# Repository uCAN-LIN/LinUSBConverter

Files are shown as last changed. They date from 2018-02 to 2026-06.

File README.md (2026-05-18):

# USB LIN Converter (uLC)





> **Open source USB ↔ LIN bus dongle. LIN 2.1 master, slave or monitor. SLCAN-compatible virtual COM port - works on Windows, Linux and macOS with no proprietary drivers.**

<p align="center">
  USB LIN Converter (uLC) - dongle photo
</p>

The **USB LIN Converter (uLC)** is a small open-source USB dongle (STM32F042C6, ~31 × 18 mm) that lets a PC act as a LIN bus master, slave or passive monitor. It enumerates as a USB CDC virtual COM port and speaks an SLCAN-style ASCII protocol, so it bridges into Linux SocketCAN via `slcand` and works with parts of can-utils.

A commercial automotive LIN analyzer typically costs hundreds to thousands of euros. This one is around **$27** on [Tindie](https://www.tindie.com/products/lll7/usb-lin-converter/).

The LIN protocol implementation is based on [openLIN](https://github.com/open-LIN).

---

## Features

- LIN 2.1 support
- **Monitor mode** - full frame reception plus single-frame transmission
- **Master mode** - up to 15 scheduled frame slots
- **Slave mode** - up to 15 scheduled frame slots for slave simulation
- 9600 / 19200 baud rate selection
- **Optical isolation** between LIN and the USB / PC side
- Software-controlled termination resistors
- External 4.5 - 28 V powers the LIN transceiver
- Device size 31 × 18 mm (without USB connector)
- USB DFU bootloader for firmware updates
- No proprietary drivers - Linux / macOS / Windows

---

## Where to buy

| Where | Region | Link |
|---|---|---|
| **Tindie** | Worldwide | https://www.tindie.com/products/lll7/usb-lin-converter/ |
| **Lectronz** | EU | https://lectronz.com/stores/ucandevices |
| **Elty** | Poland / EU | https://elty.pl/ |
| **Kamami** | Poland / EU | https://kamami.pl/ |

---

## Quickstart

1. Plug the device into a USB port. It enumerates as a virtual COM port (`COM3` on Windows, `/dev/ttyACM0` on Linux, `/dev/cu.usbmodem*` on macOS).
2. On Windows, install the [ST Virtual COM Port driver](https://www.st.com/en/development-tools/stsw-stm32102.html). On Linux and macOS no driver is required.
3. Open the port at any baud rate (USB CDC ignores baud). Line ending must be CR (`0x0D`).
4. Power the LIN side with 4.5 - 28 V on the external supply pin.
5. Send `S0` to select 19200 baud, then `l` to enter monitor mode. Bus traffic will start to appear.

### Linux SocketCAN bridge

```bash
sudo slcand -o -s8 -t hw -S 921600 /dev/ttyACM0 slcan0
sudo ip link set slcan0 up
candump slcan0
```

### Python (pyserial) sniff snippet

```python
import serial
ser = serial.Serial('/dev/ttyACM0', timeout=1)
ser.write(b'S0\r')   # 19200 baud
ser.write(b'l\r')    # monitor mode
while True:
    line = ser.readline()
    if line:
        print(line.decode(errors='replace').strip())
```

A higher-level Python library is provided in [`python_lib/`](python_lib/) (package `ucanlintools`).

---

## ASCII command reference

All commands are ASCII terminated with CR (`0x0D`). Errors return `0x07` (BEL).

| Command | Description |
|---|---|
| `O` | Open in master mode |
| `L` | Open in slave mode |
| `l` | Open in monitor mode |
| `C` | Close LIN port |
| `Sx` | Baud: `S2` = 9600, others = 19200 |
| `V` / `v` / `N` | Hardware / firmware version / serial number query |
| `tiiildd...` | Transmit full header + data frame (id, length, data) |
| `r0iil` | Header only request (slave answers) |
| `r1ff0` | Master mode: start sending frames from schedule table |
| `r2ff0` | Clear schedule table |
| `xm` | Switch checksum: `x2` classic, `x1` enhanced |
| `T0iit1t1t2t2ldd...` | Custom frame with explicit offset (`t1`) and response wait time (`t2`) |

Full command reference and examples: https://ucandevices.github.io/ulc.html

---

## Repository layout

| Directory | Contents |
|---|---|
| [`embedded/`](embedded/) | STM32F042C6 firmware sources (STM32CubeMX project `LUCEmbedded.ioc`, Atollic TrueSTUDIO project under `embedded/TrueSTUDIO/`). USB layer generated with STM32CubeMX. |
| [`pcb/`](pcb/) | Open-hardware KiCad project for the LIN_USB_CONVERTER board, Gerbers and 1-click BOM. |
| [`python_lib/`](python_lib/) | `ucanlintools` Python package with high-level master / slave / monitor helpers and examples. |
| [`doc/`](doc/) | LIN 2.2A specification, MCU datasheet, LIN transceiver datasheet and supporting documents. |

---

## Build

Source is pure C. The firmware can be imported directly into **Atollic TrueSTUDIO for STM32 9.0.0** from `embedded/TrueSTUDIO/`. The USB CDC layer was generated with STM32CubeMX from `embedded/LUCEmbedded.ioc`.

## Bootloader

The STM32F042 has an embedded ROM USB DFU bootloader. To enter it from a running device send `boot\r` over the virtual COM port. See this [tutorial](https://www.youtube.com/watch?v=-gnX25AGyI0) for the flashing flow.

---

## FAQ

**What is the cheapest USB LIN bus converter that works on Linux?**
The uCanDevices USB LIN Converter (uLC) is an open source dongle around $27 that enumerates as a USB CDC virtual COM port on Linux, macOS and Windows. It uses an SLCAN-style ASCII protocol so it bridges into SocketCAN via `slcand`.

**Does it support master and slave mode?**
Yes - monitor (full reception plus single-frame transmission), master (up to 15 scheduled slots) and slave (up to 15 slots for slave simulation). Modes are selected with the `O`, `L` and `l` commands.

**Is the LIN side optically isolated from the USB host?**
Yes. The LIN transceiver is optically isolated from the PC side, protecting the host from automotive transients. The LIN side needs an external 4.5 - 28 V supply since USB only powers the MCU.

**Which LIN baud rates and LIN version are supported?**
LIN 2.1, with selectable 9600 and 19200 baud. Classic and enhanced checksum are switchable with the `xm` command. Custom frame timing is supported in master mode.

**Can I use it to flash an ECU over LIN?**
It is a generic LIN interface. ECU flashing depends entirely on the target ECU's own LIN bootloader; if that bootloader is documented or already supported by an existing tool, you can drive it through this dongle.

**Is the firmware open source?**
Yes - this repository contains firmware (`embedded/`), hardware (`pcb/`) and the Python helper library (`python_lib/`). The device also has a USB DFU bootloader for in-field updates.

---

## Related projects

- LIN protocol implementation: [openLIN](https://github.com/open-LIN)
- Sibling products: [USB CAN Converter (UCCB)](https://ucandevices.github.io/uccb.html), [CAN FD USB Converter (CFUC)](https://ucandevices.github.io/cfuc.html), [SENT (J2716) USB Converter](https://ucandevices.github.io/sentusb.html)

## Links

- Product page: https://ucandevices.github.io/ulc.html
- All uCanDevices products: https://ucandevices.github.io/
- Contact: devices.ucan@gmail.com

## License

See [LICENSE](LICENSE).

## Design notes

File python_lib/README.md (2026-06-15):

# ucanlintools — Python library for the uCAN LIN USB Converter

`ucanlintools` is a Python 3 library for driving the
[uCAN LIN USB Converter](https://ucandevices.github.io/ulc.html) and for
working with LIN Description Files (LDF). It lets a PC act as a LIN **master**,
**slave**, or passive **monitor**, transmit/receive LIN frames, and
encode/decode signals described in an LDF.

It works on Windows, Linux and macOS. The converter enumerates as a USB CDC
virtual serial port (STMicroelectronics VID `0483` / PID `5740`).

---

## Installation

```bash
pip install ucanlintools          # from PyPI
# or, from a checkout of this repo:
pip install pyserial lark bitstruct
```

Dependencies: `pyserial` (serial I/O), `lark` (LDF grammar), `bitstruct`
(signal packing). `lark` and `bitstruct` are only needed if you use the LDF /
signal features; `LUC` itself needs only `pyserial`.

---

## Mental model (read this first)

A LIN converter is configured in three phases. **Order matters.**

1. **Configure (port is "closed" / in CONFIG state).**
   Open the port, pick a mode (`openAsMaster` / `openAsSlave` /
   `openAsMonitor`), set bus speed, and register frames in the schedule table.
   In this phase every command **reads and verifies its reply**, so the
   methods return `True`/`False` reliably.

2. **Run.** Call `enable()`. This starts two background threads that
   continuously read the serial port and dispatch received frames to your
   handler(s). **In master/slave mode this also starts the schedule.**

3. **Stop.** Call `disable()` to stop the threads, then `deInitSerial()` to
   close the port.

> ⚠️ **Key concurrency rule.** Once `enable()` has been called, the background
> rx thread owns all serial reads. Commands you send while running
> (e.g. `addTransmitFrameToTable` to update a payload) are written to the
> device but their reply is consumed by the rx thread, so those calls return
> `True` immediately without confirmation. **Do all table setup *before*
> `enable()` when you need a confirmed result.**

The three modes:

| Mode | Method | Role on the bus |
|---|---|---|
| Master  | `openAsMaster()`  | Sends headers on a schedule; transmits its table frames and polls slave frames. |
| Slave | `openAsSlave()` | Responds to a master's headers with the frames in its transmit table. |
| Monitor | `openAsMonitor()` | Passive listener; can also inject a single frame on demand (see below). |

---

## API reference (`ucanlintools.LUC`)

```python
from ucanlintools.LUC import LUC
lin = LUC(port, timeout=0.02, baudrate=9600)
```

`LUC(port, timeout=0.02, baudrate=9600)` — open the converter on `port`
(e.g. `"COM3"` or `"/dev/ttyACM0"`). **Use `baudrate=19200`**; the default
`9600` is known to corrupt frames (see *Troubleshooting*).

### Configuration commands (call before `enable()`)

| Method | Sends | Returns | Notes |
|---|---|---|---|
| `requestFirmwareVersion()` | `v` | firmware string, e.g. `"0300"` | |
| `close()` | `C` | `True` on ack | Returns the converter to CONFIG state. Safe to call first. |
| `highSpeed()` | `S1` | `True` on ack | 19200 baud LIN bus. |
| `lowSpeed()` | `S2` | `True` on ack | 9600 baud LIN bus. |
| `openAsMaster()` | `O` | `True` on ack | |
| `openAsSlave()` | `L` | `True` on ack | |
| `openAsMonitor()` | `l` | `True` on ack | |
| `addTransmitFrameToTable(id, data)` | `t…` | `True` on ack | Register a frame the node will send. `data` is `bytes` (preferred) or `int`. |
| `addReceptionFrameToTable(id, length)` | `r…` | `True` on ack | Register a frame id (and its byte `length`) the node should receive. |

### Runtime commands

| Method | Description |
|---|---|
| `enable()` | Start the rx threads and (master/slave) the schedule. Returns `1`. Call exactly once per `LUC` instance. |
| `disable()` | Stop the rx threads and reception. Idempotent. *(In monitor mode its return value is unreliable — see Limitations — but it still stops correctly.)* |
| `deInitSerial()` | Flush and close the serial port. Idempotent. |
| `isRunning()` | `True` while the rx thread is alive. Handy for blocking main loops. |

### Reception handlers

| Method | When the handler fires |
|---|---|
| `set_frame_rx_handler(fn)` | On **every** received frame. |
| `set_new_frame_rx_handler(fn)` | Only when a frame's **data changed** since the last time that id was seen. |

The handler receives a frame object with `.id` (int) and `.data` (bytes).
Handlers run in the rx thread.

---

## Example: Master mode

```python
import time
from ucanlintools.LUC import LUC

def on_frame(f):
    print(f"0x{f.id:02x}: {f.data.hex()}")

lin = LUC("COM3", baudrate=19200)
lin.set_new_frame_rx_handler(on_frame)

# --- configure (verified) ---
lin.close()
lin.highSpeed()
lin.openAsMaster()
lin.addTransmitFrameToTable(0x01, b"\x22\x33")  # master sends id 1 = 22 33
lin.addReceptionFrameToTable(0x34, 8)           # master polls id 0x34 (8 bytes)

# --- run ---
lin.enable()              # schedule starts now
time.sleep(2)

# Update a payload while running (fire-and-forget, returns True):
lin.addTransmitFrameToTable(0x01, b"\xAA\x55")
time.sleep(2)

# --- stop ---
lin.disable()
lin.deInitSerial()
```

## Example: Slave mode

```python
import time
from ucanlintools.LUC import LUC

lin = LUC("COM33", baudrate=19200)
lin.set_new_frame_rx_handler(lambda f: print("from master:", f.data.hex()))

lin.close()
lin.lowSpeed()
lin.openAsSlave()
lin.addReceptionFrameToTable(0x0B, 1)   # listen for id 0x0B from the master
lin.addTransmitFrameToTable(0x0C, b"\x00\x00")  # respond to id 0x0C
lin.enable()

time.sleep(5)
lin.disable()
lin.deInitSerial()
```

## Example: Monitor mode (passive sniff + frame injection)

```python
import time
from ucanlintools.LUC import LUC

lin = LUC("COM3", baudrate=19200)
lin.set_frame_rx_handler(lambda f: print(f"0x{f.id:02x}: {f.data.hex()}"))

lin.close()
lin.highSpeed()
lin.openAsMonitor()
lin.enable()

# In monitor mode, addTransmitFrameToTable injects ONE frame immediately:
lin.addTransmitFrameToTable(0x16, b"\x11\x22\x33")

time.sleep(2)
lin.disable()
lin.deInitSerial()
```

> **Monitor self-loopback note:** because the LIN transceiver also reads the
> bus while driving it, a frame you inject in monitor mode is echoed back to
> your handler — but only its **header** (the id with an *empty* payload), not
> the data bytes. To verify full data payloads you need a second node (a master
> or slave) on the bus.

## Example: clean shutdown on Ctrl-C

```python
import time

def listen(lin):
    try:
        while lin.isRunning():
            time.sleep(1)
    except (KeyboardInterrupt, SystemExit):
        lin.disable()
        lin.deInitSerial()
```

---

## LDF parsing and signal encode/decode

```python
from ucanlintools.LDF_parser import parseLDF

ldf = parseLDF("my_network.ldf")
frame = ldf.get_message_by_name("FRAME_A")    # or .get_message_by_id(52)

# Encode named signals into the raw payload bytes:
payload = frame.encode({"SIGNAL_A": 1})        # -> b'\x01'

# Decode raw bytes back into signal values:
frame.decode(b"\x00")
print(frame.diff_str())                        # -> {'SIGNAL_A' : 0}
```

`diff_str()` returns only the signals whose value changed since the previous
call (useful for compact logging).

Tie it together — decode received frames against an LDF:

```python
frame = ldf.get_message_by_id(52)

def on_new(f):
    if f.id == frame.id:
        frame.decode(f.data)
        print(frame.diff_str())

lin.set_new_frame_rx_handler(on_new)
```

---

## Limitations / gotchas

- **Use `baudrate=19200`.** The default `9600` causes intermittent frame
  corruption (frames silently dropped on a parse error).
- **Configure before `enable()`** for verified table setup; calls made after
  `enable()` return `True` without confirmation (rx thread owns reads).
- **Monitor mode:** injected frames loop back as headers only (no payload);
  and `disable()` may return `False` in monitor mode even though it stopped
  correctly (the stop command is itself echoed on the bus, contaminating the
  reply). The threads are still stopped.
- **LDF support is partial:** only `Signals` and `Frames` sections are used;
  schedule tables, encoding types and node attributes are parsed but ignored.
  Maximum signal size is 1 byte.
- `enable()` may be called only once per `LUC` instance (threads can't be
  restarted). Create a new `LUC` to run again.

---

## Tests

The test suite is pytest-based and lives in `tests/`:

- **Offline tests** (no hardware): `test_ldf_parser.py`, `test_linframe.py`,
  `test_luc_encoding.py`.
- **Hardware tests** (`test_luc_hardware.py`): single-dongle tests use the
  port from `LUC_MASTER_PORT` (default `COM3`); the two-dongle master↔slave
  test also needs `LUC_SLAVE_PORT` (default `COM33`). Hardware tests **skip
  automatically** if the required dongle can't be opened.

```bash
cd python_lib
pip install pytest
# run everything that doesn't need hardware + any reachable dongles:
PYTHONPATH=. pytest tests -v
# point at your dongles:
LUC_MASTER_PORT=COM3 LUC_SLAVE_PORT=COM33 PYTHONPATH=. pytest tests -v
```

On Windows PowerShell, set the env vars with `$env:PYTHONPATH="."` etc.

---

## Underlying serial (SLCAN-style) protocol — reference for tooling

Commands are ASCII, terminated by `\r`. Replies are terminated by `\r`.

| Command | Meaning | Reply |
|---|---|---|
| `v` | firmware version | `vMMmm` |
| `V` | hardware version | `VMMmm` |
| `O` / `L` / `l` | open master / slave / monitor | `\r` |
| `C` | close (back to config) | `\r` |
| `S1` / `S2` | bus speed 19200 / 9600 | `\r` |
| `t0<id><len><data…>` | transmit frame (table entry, or immediate in monitor) | `z\r` |
| `r0<id><len>` | reception table entry | `z\r` |
| `r1ff0` | start schedule / reception (sent by `enable()`) | `z\r` |
| `r2ff0` | stop (sent by `disable()`) | `z\r` |
| received frame | reported by the device | `t0<id><len><data…>\r` |

`<id>` is 2 hex digits, `<len>` is 1 hex digit (0–8), `<data…>` is `len` bytes
as hex pairs.

## More info

- Hardware & docs: https://ucandevices.github.io
- Source: https://github.com/uCAN-LIN/LinUSBConverter/tree/master/python_lib

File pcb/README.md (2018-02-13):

Printed circuit board for LinUSBConverter. Project is made in KiCad.

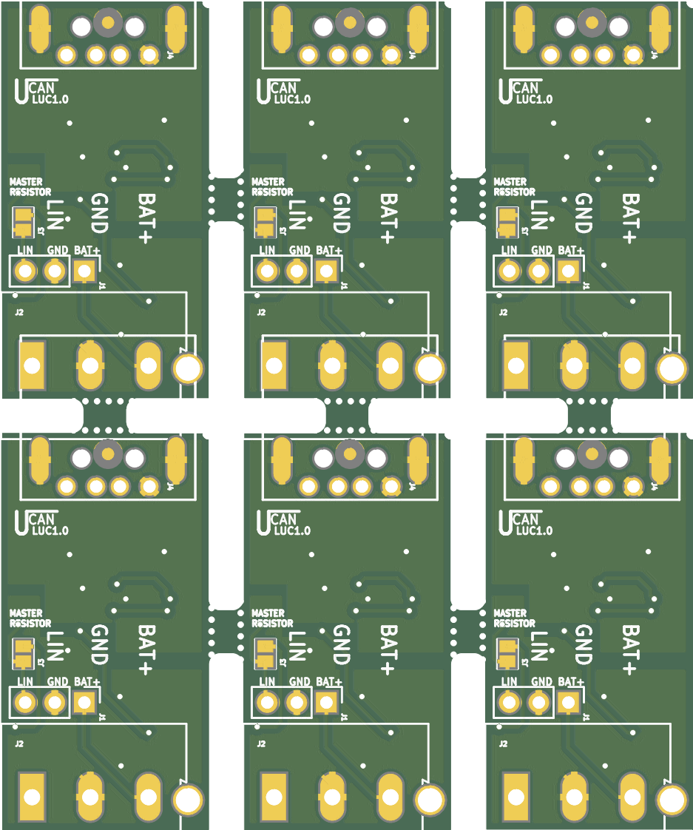
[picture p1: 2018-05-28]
pcb/luc_panel/pcb/pan_Combined_Bottom.png

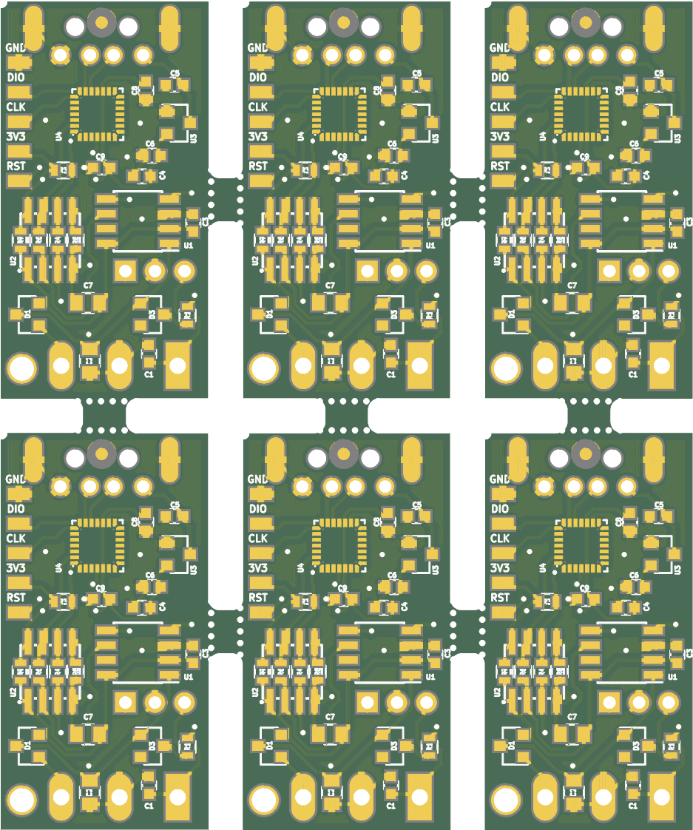
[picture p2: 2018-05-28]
pcb/luc_panel/pcb/pan_Combined_Top.png

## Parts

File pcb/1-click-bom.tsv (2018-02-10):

References | Qty | Description
C1 | 1 | CP1 Small 220p Polarised capacitor C 0603
C2 | 1 | CP1 Small 1u Polarised capacitor C 0603
C8 | 1 | C 10n Unpolarized capacitor 0402
C9, C5, C6, C3, C4 | 5 | C 100n Unpolarized capacitor 0402
D1, D3 | 2 | D Small ALT SMBD914E6327HTSA1 Diode, small symbol, alternativ symbol SOT-23 ANK
D2 | 1 | D Schottky Small ALT 1N5819HW-7-F diode, small symbol, alternativ symbol SOD-123
J1 | 1 | Conn 01x03 Generic connector, single row, Pin Header Straight 1x03 Pitch2.54mm
J2 | 1 | Conn 01x03 Generic connector, single row, TerminalBlock Altech AK300-3 P5.00mm
J3 | 1 | GS2 2-pin jumper/solder bridge
J4 | 1 | USB A Type connector DS1097R
J5 | 1 | Conn 01x02 Generic connector, single row, Pin Header Straight 1x02 Pitch2.54mm
P2 | 1 | CONN 01X05 swd smd conn5
R1 | 1 | R 1k Resistor 0603
R2 | 1 | R 50 Resistor 0603
R5, R3 | 2 | R 10k Resistor 0603
R6, R4, R7, R8 | 4 | R 0 Resistor 0603
U1 | 1 | TJA1028 HVSON8
U2 | 1 | MAX12931 SOIC-8-N
U3 | 1 | MCP1700T-3302E/TT SOT-23
U4 | 1 | STM32F042C6T6 STM32F042G4U6 UFQFPN 28
f1, f2 | 2 | fiducial Fiducial 1mm Dia 2.54mm Outer CopperTop
mh1 | 1 | fiducial 1pin

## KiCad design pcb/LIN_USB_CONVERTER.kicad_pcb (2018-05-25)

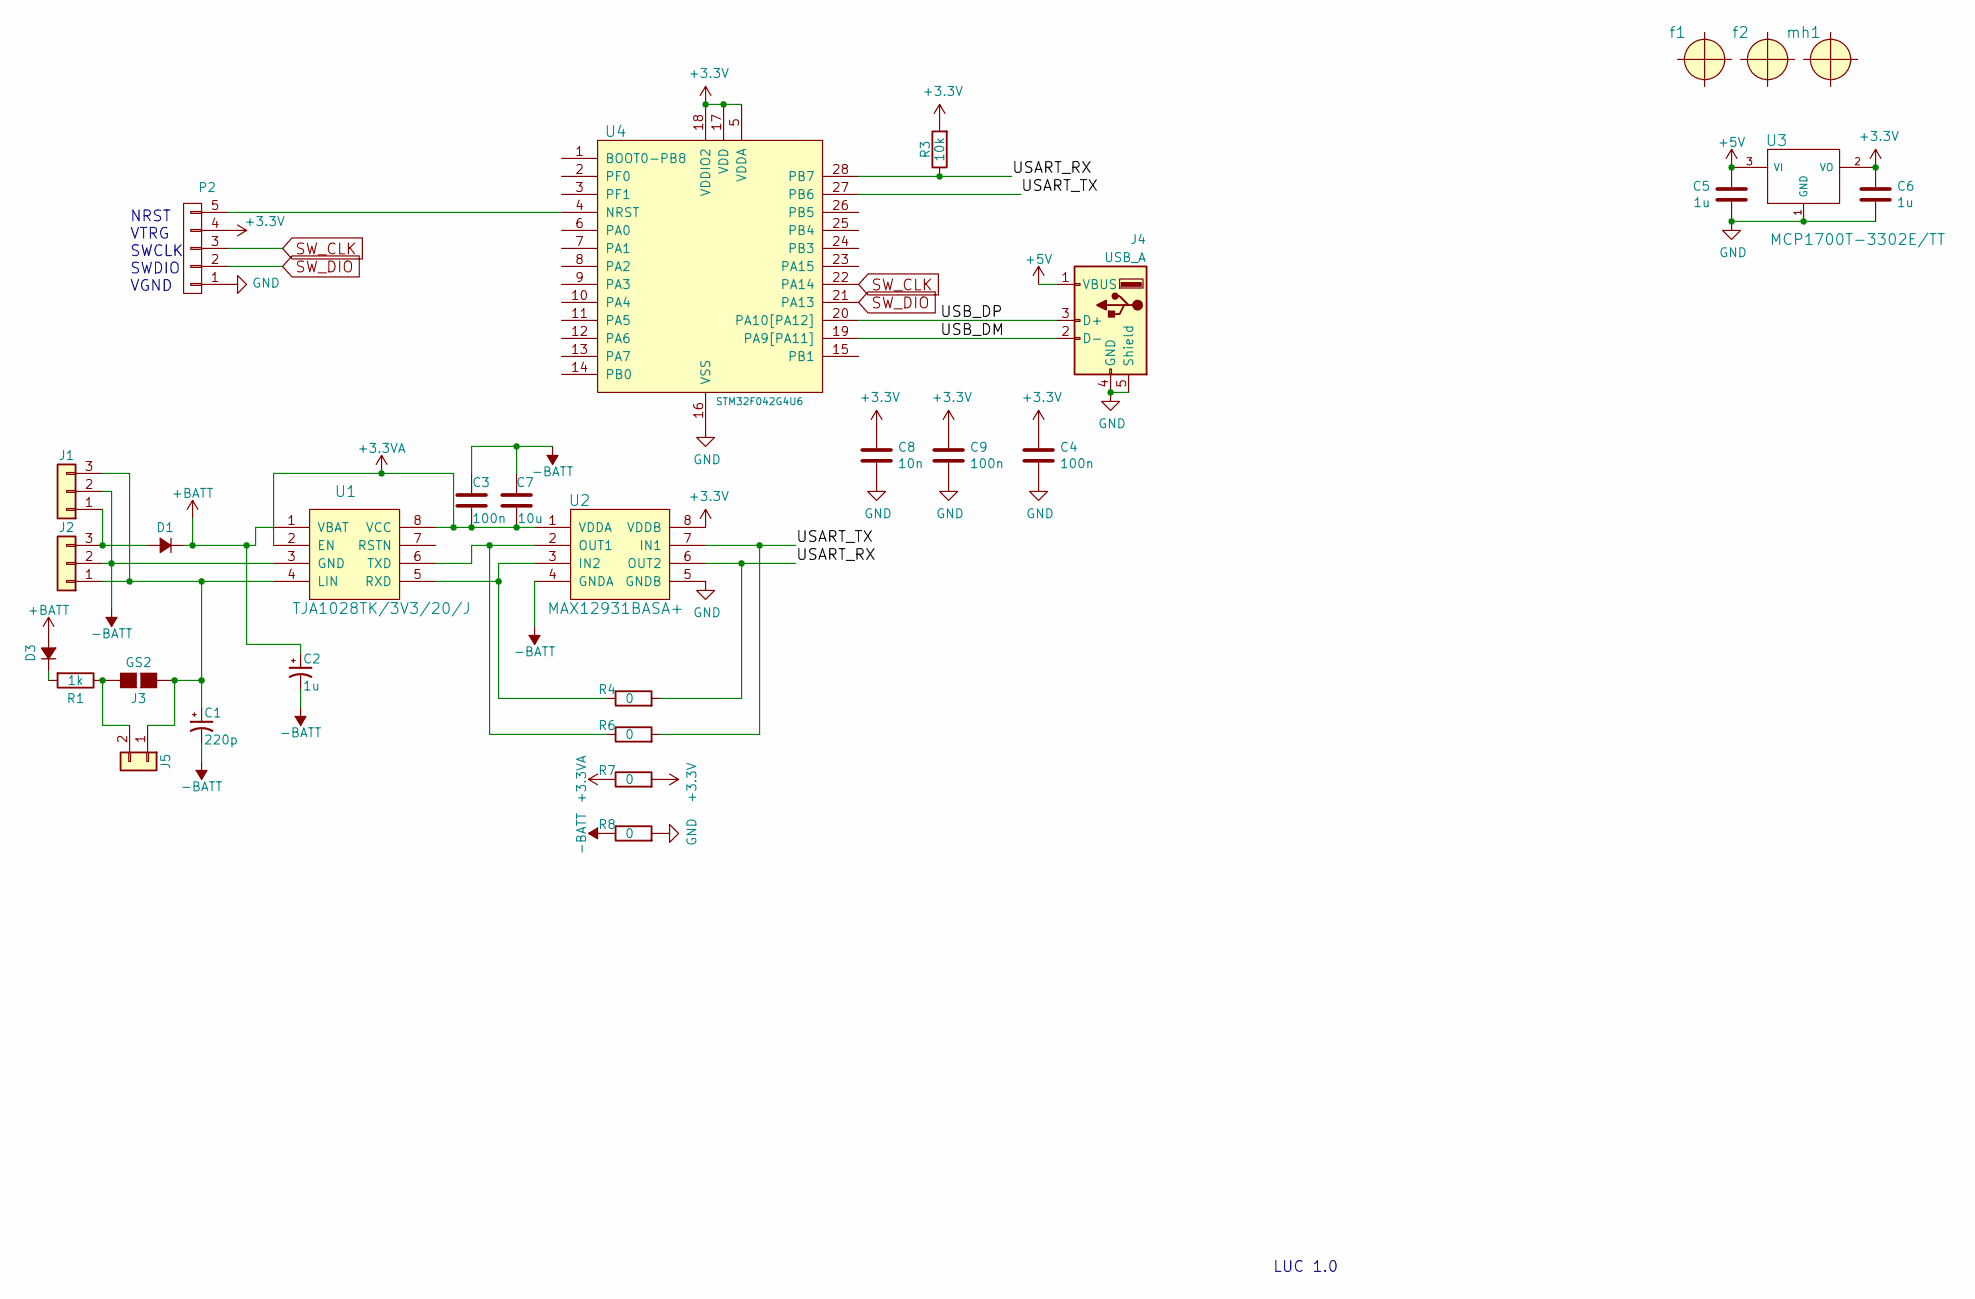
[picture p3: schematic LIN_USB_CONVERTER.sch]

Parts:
C1: 220p; C_0603
C2: 1u; C_0805
C3, C4, C9: 100n; C_0603
C5, C6: 1u; C_0603
C7: 10u; C_0805
C8: 10n; C_0603
D1, D3: SMBD914E6327HTSA1; D_SOT-23_ANK
J1: Conn_01x03; Pin_Header_Straight_1x03_Pitch2.54mm
J2: TerminalBlock; TerminalBlock_Altech_AK300-3_P5.00mm
J3: GS2
J4: USB_A; USB_A_DS1097R
J5: Conn_01x02; Pin_Header_Straight_1x02_Pitch2.54mm
P2: CONN_01X05; swd_smd_conn5
R1: 1k; R_0603
R3: 10k; R_0603
R4, R6, R7, R8: 0; R_0603
U1: TJA1028TK/3V3/20/J; SOIC-8_3.9x4.9mm_Pitch1.27mm
U2: MAX12931BASA+; SOIC-8-N_MAXIM
U3: MCP1700T-3302E/TT; SOT-23
U4: STM32F042G4U6; ST_UFQFPN-28_3x3mm_P0.5mm; MFG Part Num STM32F042G4U6
f1, f2: fiducial; Fiducial_1mm_Dia_2.54mm_Outer_CopperTop
mh1: fiducial; 1pin

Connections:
+3.3VA: C3.2, C7.2, R7.1, U1.2 (EN), U1.8 (VCC), U2.1 (VDDA)
+3V3: C4.1, C6.1, C8.1, C9.1, P2.4, R3.2, R7.2, U2.8 (VDDB), U3.2 (VO), U4.5 (VDDA), U4.17 (VDD), U4.18 (VDDIO2)
+5V: C5.1, J4.1 (VBUS), U3.3 (VI)
+BATT: C2.1, D1.1 (K), D3.2 (A), U1.1 (VBAT)
-BATT: C1.2, C2.2, C3.1, C7.1, J1.2, J2.2, R8.1, U1.3 (GND), U2.4 (GNDA)
/USART_RX: R3.1, R4.2, U2.6 (OUT2), U4.28 (PB7)
/USART_TX: R6.2, U2.7 (IN1), U4.27 (PB6)
/USB_DM: J4.2 (D-), U4.19 (PA9[PA11])
/USB_DP: J4.3 (D+), U4.20 (PA10[PA12])
GND: C4.2, C5.2, C6.2, C8.2, C9.2, J4.4 (GND), J4.5 (Shield), P2.1, R8.2, U2.5 (GNDB), U3.1 (GND), U4.16 (VSS)
unnamed: C1.1, J1.3, J2.1, J3.1 (G1), J5.1, U1.4 (LIN)
unnamed: D1.2 (A), J1.1, J2.3
unnamed: D3.1 (K), R1.2
unnamed: J3.2 (G2), J5.2, R1.1
unnamed: P2.5, U4.4 (NRST)
unnamed: R4.1, U1.5 (RXD), U2.3 (IN2)
unnamed: R6.1, U1.6 (TXD), U2.2 (OUT1)
SW_CLK: P2.3, U4.22 (PA14)
SW_DIO: P2.2, U4.21 (PA13)

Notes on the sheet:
NRST VTRG SWCLK SWDIO VGND
LUC 1.0

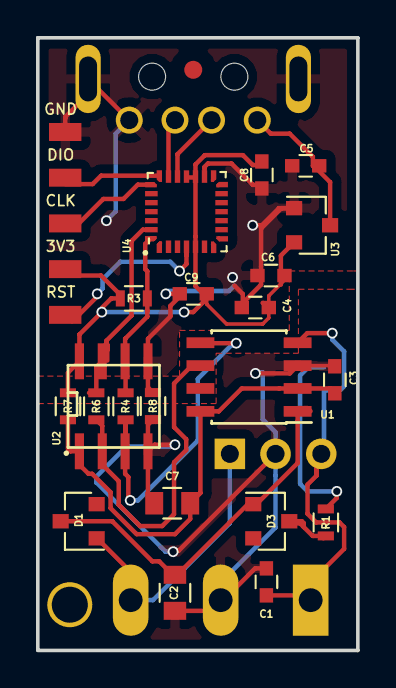
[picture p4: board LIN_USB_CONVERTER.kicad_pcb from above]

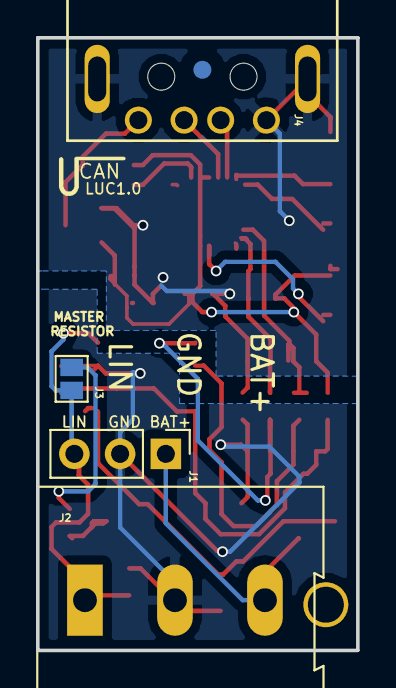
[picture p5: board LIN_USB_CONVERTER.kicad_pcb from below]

Board: 2 copper layers, 17.8 x 34.0 mm, 29 parts (5 on the bottom side), 19 nets.

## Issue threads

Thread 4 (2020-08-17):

Starting slave mode uses incorrect type in function call

ryedwards, 2020-08-17:
Investigating why loading my slave data table is not triggering responses.  I found the following in the code:

In lin_slcan.c:
```
t_master_frame_table_item master_frame_table[MAX_SLAVES_COUNT];
.
.
.
//start sending
if (line[1] == '1'){
  if (lin_type == LIN_SLAVE)
    	{
    		open_lin_net_init(master_frame_table,master_frame_table_size);
    	} else {
			open_lin_master_dl_init(master_frame_table,master_frame_table_size);
    		 //wakeUpLin();
    	}
        slcan_state = SLCAN_STATE_OPEN;
        return 1;
```
Issue is that open_lin_init is expecting
```
void open_lin_net_init(open_lin_frame_slot_t *a_slot_array, l_u8 a_slot_array_len)
```

Going to try and fix the issue myself but wondering if there was a reason for using a different type?

Lukasz-Juranek, 2020-08-17:
Thanks for pointing this out, You are using outdated open-LIN-c submodule.
I'm not sure why :) but i've changed some time ago signature of
*open_lin_net_init
*to
void open_lin_net_init(t_master_frame_table_item *a_slot_array, l_u8
a_slot_array_len)

I've put new barnch
https://github.com/open-LIN/open-LIN-c/tree/open_lin_net_init_type_Issue
for  open-LIN-c
related to this issue, with updated *open-LIN-c *submodule please see it.
 Next week i'll try to clean up this mess and do some integration.

Thanks for feedback

pon., 17 sie 2020 o 19:33 Ryan Edwards <notifications@github.com>
napisał(a):

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

ryedwards, 2020-08-17:
Thanks,

In the meantime I changed the function call to:

``
open_lin_net_init(&master_frame_table->slot,master_frame_table_size);
``

Everything seems to be working but I haven't dug too deep.  I'll port over updates once you have them available.  Code is working great.  I did update the STM32 handler to receive commands over UART2 vs. USB_CDC for a project I am working on.  Works well so far.

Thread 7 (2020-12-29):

Impossible to recover from L slave mode is serial connection if abruptly disconnected

AleksandarFilipov, 2020-12-29:
reproduce:
minicom (se how to configure for desired tty)
```
C
L
r0002
r1ff0
```
now abruptly disconnect in minicom; this is hit (to show menut) `esc Z`, hit `Quit with no reset.Q`
reconnect, serial communication is now open but there is no response from device. No command are operational. Exampel `v` doesn't responde anything.

-> solution for now, unplug/replug device.

Interesting, the same works nice for `l` mode.

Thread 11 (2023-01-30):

SLCAND Monitor Mode: No Frames from Lin Slave

menschel, 2023-01-30:
Hello,

I recently tried to use your LUC on a raspberry pi running
```
sudo slcand -ol -s1 /dev/ttyACM0 lin0
sudo ip link set lin0 up
candump -td lin0
```

With this approach, no frame from the LIN slave is shown in candump, only the frames from LIN master.

On the other hand, using your [uCCBViewer](https://github.com/UsbCANConverter-UCCbasic/uCCBViewer/releases) on a Windows machine with setting "Monitor Mode", it does show the frames from the LIN slave.  However this setup is useless for me because I work on socketcan .

What is the difference that causes this behavior? Please advise.
Thank you.

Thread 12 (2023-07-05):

usb library heap and stack sizes

CheAhMeD, 2023-07-05:
Hello
I tried to replicate the board with a different mcu (STM32F042K6T6: same but bigger flash) with no success including the USB_DEVICE library using CubeIDE. I get some errors while compiling _user_heap_stack will not fit and '.text' will not fit.
This is without including the open-lin library!
Is there something I am missing here?

thank you

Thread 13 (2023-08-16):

Fails to compile with Atollic TrueSTUDIO for STM32

phansel, 2023-08-16:
# IDE
Atollic TrueSTUDIO® for STM32, Built on Eclipse Neon.1a.
Version: 9.3.0
Build id: 20190212-0734

# Tag
HEAD detached at 1.5

# System
6.4.10-arch1-1 #1 SMP PREEMPT_DYNAMIC x86_64

# Objective
Modify source to change 19200/9600 baud to 10400 baud.

# Expected result
Successful binary compilation with unmodified source tree

# Result
Immediate compilation failure related to dependency recursion.

# CDT Global Build Console Log
```
14:03:09 **** Clean-only build of configuration Debug for project embedded ****
rm -rf Src/system_stm32f0xx.d Drivers/STM32F0xx_HAL_Driver/Src/stm32f0xx_hal.o Drivers/STM32F0xx_HAL_Driver/Src/stm32f0xx_hal_tim.d Drivers/STM32F0xx_HAL_Driver/Src/stm32f0xx_hal_flash_ex.d Drivers/STM32F0xx_HAL_Driver/Src/stm32f0xx_hal_tim_ex.d Drivers/STM32F0xx_HAL_Driver/Src/stm32f0xx_hal_cortex.d Drivers/STM32F0xx_HAL_Driver/Src/stm32f0xx_hal_tim_ex.o Drivers/STM32F0xx_HAL_Driver/Src/stm32f0xx_hal_tim.o Middlewares/ST/STM32_USB_Device_Library/Core/Src/usbd_core.d Src/usbd_desc.o Middlewares/ST/STM32_USB_Device_Library/Class/CDC/Src/usbd_cdc.o Drivers/STM32F0xx_HAL_Driver/Src/stm32f0xx_hal_dma.d Drivers/STM32F0xx_HAL_Driver/Src/stm32f0xx_hal_rcc_ex.o Src/slcan.d TrueSTUDIO/startup_stm32f042x6.o Drivers/STM32F0xx_HAL_Driver/Src/stm32f0xx_hal_pcd_ex.o Src/slcan.o Middlewares/ST/STM32_USB_Device_Library/Class/CDC/Src/usbd_cdc.d Src/usbd_desc.d Src/main.o Src/main.d Middlewares/ST/STM32_USB_Device_Library/Core/Src/usbd_core.o Drivers/STM32F0xx_HAL_Driver/Src/stm32f0xx_hal_rcc_ex.d Src/bootloader.d Drivers/STM32F0xx_HAL_Driver/Src/stm32f0xx_hal_pwr_ex.d Drivers/STM32F0xx_HAL_Driver/Src/stm32f0xx_hal_flash.o Middlewares/ST/STM32_USB_Device_Library/Core/Src/usbd_ctlreq.o Middlewares/ST/STM32_USB_Device_Library/Core/Src/usbd_ioreq.d Drivers/STM32F0xx_HAL_Driver/Src/stm32f0xx_hal_uart.o Drivers/STM32F0xx_HAL_Driver/Src/stm32f0xx_hal_uart.d Middlewares/ST/STM32_USB_Device_Library/Core/Src/usbd_ctlreq.d Src/bootloader.o Middlewares/ST/STM32_USB_Device_Library/Core/Src/usbd_ioreq.o Drivers/STM32F0xx_HAL_Driver/Src/stm32f0xx_hal_flash.d Drivers/STM32F0xx_HAL_Driver/Src/stm32f0xx_hal_rcc.o Drivers/STM32F0xx_HAL_Driver/Src/stm32f0xx_hal_i2c_ex.d Drivers/STM32F0xx_HAL_Driver/Src/stm32f0xx_hal_pcd_ex.d Drivers/STM32F0xx_HAL_Driver/Src/stm32f0xx_hal_rcc.d Drivers/STM32F0xx_HAL_Driver/Src/stm32f0xx_hal_i2c_ex.o Drivers/STM32F0xx_HAL_Driver/Src/stm32f0xx_hal_dma.o Drivers/STM32F0xx_HAL_Driver/Src/stm32f0xx_hal_i2c.o Drivers/STM32F0xx_HAL_Driver/Src/stm32f0xx_hal_cortex.o embedded Src/lin_slcan.o Src/usbd_conf.o Src/lin_slcan.d Src/usbd_cdc_if.d Drivers/STM32F0xx_HAL_Driver/Src/stm32f0xx_hal_pwr.d Drivers/STM32F0xx_HAL_Driver/Src/stm32f0xx_hal_flash_ex.o Src/stm32f0xx_it.o Src/usb_device.d embedded.elf Src/usbd_cdc_if.o Drivers/STM32F0xx_HAL_Driver/Src/stm32f0xx_hal_pcd.d Src/stm32f0xx_hal_msp.d Src/stm32f0xx_it.d Src/usb_device.o Src/system_stm32f0xx.o Drivers/STM32F0xx_HAL_Driver/Src/stm32f0xx_hal_gpio.d Drivers/STM32F0xx_HAL_Driver/Src/stm32f0xx_hal_uart_ex.d Src/usbd_conf.d Drivers/STM32F0xx_HAL_Driver/Src/stm32f0xx_hal_pwr_ex.o Drivers/STM32F0xx_HAL_Driver/Src/stm32f0xx_hal_uart_ex.o Src/stm32f0xx_hal_msp.o Drivers/STM32F0xx_HAL_Driver/Src/stm32f0xx_hal_pcd.o Drivers/STM32F0xx_HAL_Driver/Src/stm32f0xx_hal_gpio.o Drivers/STM32F0xx_HAL_Driver/Src/stm32f0xx_hal.d Drivers/STM32F0xx_HAL_Driver/Src/stm32f0xx_hal_i2c.d Drivers/STM32F0xx_HAL_Driver/Src/stm32f0xx_hal_pwr.o

14:03:10 Build Finished (took 956ms)

14:03:13 **** Incremental Build of configuration Debug for project LUCEmbedded ****
Info: Internal Builder is used for build
arm-atollic-eabi-gcc -c -mthumb -mcpu=cortex-m0 -std=gnu11 -D__weak=__attribute__((weak)) -D__packed=__attribute__((__packed__)) -DUSE_HAL_DRIVER -DSTM32F042x6 -I../../../Inc -I../../../Drivers/STM32F0xx_HAL_Driver/Inc -I../../../Drivers/STM32F0xx_HAL_Driver/Inc/Legacy -I../../../Middlewares/ST/STM32_USB_Device_Library/Core/Inc -I../../../Middlewares/ST/STM32_USB_Device_Library/Class/CDC/Inc -I../../../Drivers/CMSIS/Device/ST/STM32F0xx/Include -I../../../Drivers/CMSIS/Include -ID:\GIThub\LinUSBConverter\embedded\Src\open-LIN-c -Os -ffunction-sections -fdata-sections -g -Wall -specs=nano.specs -o Middlewares/USB_Device_Library/usbd_cdc.o ../../../Middlewares/ST/STM32_USB_Device_Library/Class/CDC/Src/usbd_cdc.c
arm-atollic-eabi-gcc -c -mthumb -mcpu=cortex-m0 -std=gnu11 -D__weak=__attribute__((weak)) -D__packed=__attribute__((__packed__)) -DUSE_HAL_DRIVER -DSTM32F042x6 -I../../../Inc -I../../../Drivers/STM32F0xx_HAL_Driver/Inc -I../../../Drivers/STM32F0xx_HAL_Driver/Inc/Legacy -I../../../Middlewares/ST/STM32_USB_Device_Library/Core/Inc -I../../../Middlewares/ST/STM32_USB_Device_Library/Class/CDC/Inc -I../../../Drivers/CMSIS/Device/ST/STM32F0xx/Include -I../../../Drivers/CMSIS/Include -ID:\GIThub\LinUSBConverter\embedded\Src\open-LIN-c -Os -ffunction-sections -fdata-sections -g -Wall -specs=nano.specs -o Drivers/STM32F0xx_HAL_Driver/stm32f0xx_hal_pcd_ex.o ../../../Drivers/STM32F0xx_HAL_Driver/Src/stm32f0xx_hal_pcd_ex.c
arm-atollic-eabi-gcc -c -mthumb -mcpu=cortex-m0 -std=gnu11 -D__weak=__attribute__((weak)) -D__packed=__attribute__((__packed__)) -DUSE_HAL_DRIVER -DSTM32F042x6 -I../../../Inc -I../../../Drivers/STM32F0xx_HAL_Driver/Inc -I../../../Drivers/STM32F0xx_HAL_Driver/Inc/Legacy -I../../../Middlewares/ST/STM32_USB_Device_Library/Core/Inc -I../../../Middlewares/ST/STM32_USB_Device_Library/Class/CDC/Inc -I../../../Drivers/CMSIS/Device/ST/STM32F0xx/Include -I../../../Drivers/CMSIS/Include -ID:\GIThub\LinUSBConverter\embedded\Src\open-LIN-c -Os -ffunction-sections -fdata-sections -g -Wall -specs=nano.specs -o Drivers/STM32F0xx_HAL_Driver/stm32f0xx_hal_pwr_ex.o ../../../Drivers/STM32F0xx_HAL_Driver/Src/stm32f0xx_hal_pwr_ex.c
arm-atollic-eabi-gcc -c -mthumb -mcpu=cortex-m0 -std=gnu11 -D__weak=__attribute__((weak)) -D__packed=__attribute__((__packed__)) -DUSE_HAL_DRIVER -DSTM32F042x6 -I../../../Inc -I../../../Drivers/STM32F0xx_HAL_Driver/Inc -I../../../Drivers/STM32F0xx_HAL_Driver/Inc/Legacy -I../../../Middlewares/ST/STM32_USB_Device_Library/Core/Inc -I../../../Middlewares/ST/STM32_USB_Device_Library/Class/CDC/Inc -I../../../Drivers/CMSIS/Device/ST/STM32F0xx/Include -I../../../Drivers/CMSIS/Include -ID:\GIThub\LinUSBConverter\embedded\Src\open-LIN-c -Os -ffunction-sections -fdata-sections -g -Wall -specs=nano.specs -o Drivers/STM32F0xx_HAL_Driver/stm32f0xx_hal_rcc.o ../../../Drivers/STM32F0xx_HAL_Driver/Src/stm32f0xx_hal_rcc.c
arm-atollic-eabi-gcc -c -mthumb -mcpu=cortex-m0 -std=gnu11 -D__weak=__attribute__((weak)) -D__packed=__attribute__((__packed__)) -DUSE_HAL_DRIVER -DSTM32F042x6 -I../../../Inc -I../../../Drivers/STM32F0xx_HAL_Driver/Inc -I../../../Drivers/STM32F0xx_HAL_Driver/Inc/Legacy -I../../../Middlewares/ST/STM32_USB_Device_Library/Core/Inc -I../../../Middlewares/ST/STM32_USB_Device_Library/Class/CDC/Inc -I../../../Drivers/CMSIS/Device/ST/STM32F0xx/Include -I../../../Drivers/CMSIS/Include -ID:\GIThub\LinUSBConverter\embedded\Src\open-LIN-c -Os -ffunction-sections -fdata-sections -g -Wall -specs=nano.specs -o Drivers/STM32F0xx_HAL_Driver/stm32f0xx_hal_rcc_ex.o ../../../Drivers/STM32F0xx_HAL_Driver/Src/stm32f0xx_hal_rcc_ex.c
arm-atollic-eabi-gcc -c -mthumb -mcpu=cortex-m0 -std=gnu11 -D__weak=__attribute__((weak)) -D__packed=__attribute__((__packed__)) -DUSE_HAL_DRIVER -DSTM32F042x6 -I../../../Inc -I../../../Drivers/STM32F0xx_HAL_Driver/Inc -I../../../Drivers/STM32F0xx_HAL_Driver/Inc/Legacy -I../../../Middlewares/ST/STM32_USB_Device_Library/Core/Inc -I../../../Middlewares/ST/STM32_USB_Device_Library/Class/CDC/Inc -I../../../Drivers/CMSIS/Device/ST/STM32F0xx/Include -I../../../Drivers/CMSIS/Include -ID:\GIThub\LinUSBConverter\embedded\Src\open-LIN-c -Os -ffunction-sections -fdata-sections -g -Wall -specs=nano.specs -o Application/User/bootloader.o ../../../Src/bootloader.c
arm-atollic-eabi-gcc -c -mthumb -mcpu=cortex-m0 -std=gnu11 -D__weak=__attribute__((weak)) -D__packed=__attribute__((__packed__)) -DUSE_HAL_DRIVER -DSTM32F042x6 -I../../../Inc -I../../../Drivers/STM32F0xx_HAL_Driver/Inc -I../../../Drivers/STM32F0xx_HAL_Driver/Inc/Legacy -I../../../Middlewares/ST/STM32_USB_Device_Library/Core/Inc -I../../../Middlewares/ST/STM32_USB_Device_Library/Class/CDC/Inc -I../../../Drivers/CMSIS/Device/ST/STM32F0xx/Include -I../../../Drivers/CMSIS/Include -ID:\GIThub\LinUSBConverter\embedded\Src\open-LIN-c -Os -ffunction-sections -fdata-sections -g -Wall -specs=nano.specs -o Middlewares/USB_Device_Library/usbd_ioreq.o ../../../Middlewares/ST/STM32_USB_Device_Library/Core/Src/usbd_ioreq.c
arm-atollic-eabi-gcc -c -mthumb -mcpu=cortex-m0 -std=gnu11 -D__weak=__attribute__((weak)) -D__packed=__attribute__((__packed__)) -DUSE_HAL_DRIVER -DSTM32F042x6 -I../../../Inc -I../../../Drivers/STM32F0xx_HAL_Driver/Inc -I../../../Drivers/STM32F0xx_HAL_Driver/Inc/Legacy -I../../../Middlewares/ST/STM32_USB_Device_Library/Core/Inc -I../../../Middlewares/ST/STM32_USB_Device_Library/Class/CDC/Inc -I../../../Drivers/CMSIS/Device/ST/STM32F0xx/Include -I../../../Drivers/CMSIS/Include -ID:\GIThub\LinUSBConverter\embedded\Src\open-LIN-c -Os -ffunction-sections -fdata-sections -g -Wall -specs=nano.specs -o Application/User/stm32f0xx_hal_msp.o ../../../Src/stm32f0xx_hal_msp.c
arm-atollic-eabi-gcc -c -mthumb -mcpu=cortex-m0 -std=gnu11 -D__weak=__attribute__((weak)) -D__packed=__attribute__((__packed__)) -DUSE_HAL_DRIVER -DSTM32F042x6 -I../../../Inc -I../../../Drivers/STM32F0xx_HAL_Driver/Inc -I../../../Drivers/STM32F0xx_HAL_Driver/Inc/Legacy -I../../../Middlewares/ST/STM32_USB_Device_Library/Core/Inc -I../../../Middlewares/ST/STM32_USB_Device_Library/Class/CDC/Inc -I../../../Drivers/CMSIS/Device/ST/STM32F0xx/Include -I../../../Drivers/CMSIS/Include -ID:\GIThub\LinUSBConverter\embedded\Src\open-LIN-c -Os -ffunction-sections -fdata-sections -g -Wall -specs=nano.specs -o Drivers/STM32F0xx_HAL_Driver/stm32f0xx_hal_pwr.o ../../../Drivers/STM32F0xx_HAL_Driver/Src/stm32f0xx_hal_pwr.c
../../../Drivers/STM32F0xx_HAL_Driver/Src/stm32f0xx_hal_rcc_ex.c: In function 'HAL_RCCEx_PeriphCLKConfig':
../../../Drivers/STM32F0xx_HAL_Driver/Src/stm32f0xx_hal_rcc_ex.c:123:12: warning: unused variable 'temp_reg' [-Wunused-variable]
   uint32_t temp_reg = 0U;
            ^~~~~~~~
../../../Drivers/STM32F0xx_HAL_Driver/Src/stm32f0xx_hal_rcc_ex.c:122:12: warning: unused variable 'tickstart' [-Wunused-variable]
   uint32_t tickstart = 0U;
            ^~~~~~~~~
arm-atollic-eabi-gcc -c -mthumb -mcpu=cortex-m0 -ID:\GIThub\LinUSBConverter\embedded\Src\open-LIN-c -Wa,--no-warn -x assembler-with-cpp -specs=nano.specs -o Application/TrueSTUDIO/startup_stm32f042x6.o ../../startup_stm32f042x6.s
arm-atollic-eabi-gcc -c -mthumb -mcpu=cortex-m0 -std=gnu11 -D__weak=__attribute__((weak)) -D__packed=__attribute__((__packed__)) -DUSE_HAL_DRIVER -DSTM32F042x6 -I../../../Inc -I../../../Drivers/STM32F0xx_HAL_Driver/Inc -I../../../Drivers/STM32F0xx_HAL_Driver/Inc/Legacy -I../../../Middlewares/ST/STM32_USB_Device_Library/Core/Inc -I../../../Middlewares/ST/STM32_USB_Device_Library/Class/CDC/Inc -I../../../Drivers/CMSIS/Device/ST/STM32F0xx/Include -I../../../Drivers/CMSIS/Include -ID:\GIThub\LinUSBConverter\embedded\Src\open-LIN-c -Os -ffunction-sections -fdata-sections -g -Wall -specs=nano.specs -o Drivers/STM32F0xx_HAL_Driver/stm32f0xx_hal_uart_ex.o ../../../Drivers/STM32F0xx_HAL_Driver/Src/stm32f0xx_hal_uart_ex.c
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

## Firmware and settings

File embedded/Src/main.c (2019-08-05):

/**
  ******************************************************************************
  * @file           : main.c
  * @brief          : Main program body
  ******************************************************************************
  * This notice applies to any and all portions of this file
  * that are not between comment pairs USER CODE BEGIN and
  * USER CODE END. Other portions of this file, whether 
  * inserted by the user or by software development tools
  * are owned by their respective copyright owners.
  *
  * Copyright (c) 2018 STMicroelectronics International N.V. 
  * All rights reserved.
  *
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
  * 1. Redistribution of source code must retain the above copyright notice, 
  *    this list of conditions and the following disclaimer.
  * 2. Redistributions in binary form must reproduce the above copyright notice,
  *    this list of conditions and the following disclaimer in the documentation
  *    and/or other materials provided with the distribution.
  * 3. Neither the name of STMicroelectronics nor the names of other 
  *    contributors to this software may be used to endorse or promote products 
  *    derived from this software without specific written permission.
  * 4. This software, including modifications and/or derivative works of this 
  *    software, must execute solely and exclusively on microcontroller or
-  *    microprocessor devices manufactured by or for STMicroelectronics.
  * 5. Redistribution and use of this software other than as permitted under 
  *    this license is void and will automatically terminate your rights under 
  *    this license. 
  *
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
  ******************************************************************************
  */
/* Includes ------------------------------------------------------------------*/
#include "main.h"
#include "stm32f0xx_hal.h"
#include "usb_device.h"

/* USER CODE BEGIN Includes */
#include "slcan.h"
#include "lin_slcan.h"


/* USER CODE END Includes */

UART_HandleTypeDef huart1;

/* USER CODE BEGIN PV */

/* USER CODE END PV */

void SystemClock_Config(void);
static void MX_GPIO_Init(void);
void MX_USART1_UART_Init(void);

/* USER CODE BEGIN PFP */

/* USER CODE END PFP */

/* USER CODE BEGIN 0 */
const uint32_t *uid = (uint32_t *)(UID_BASE);
uint32_t serialNumber = 0;
uint8_t Uart2RxFifo;
uint32_t lin_baund_rate = 19200;
#define UART_RX_FIFO_SIZE 1
/* USER CODE END 0 */

/**
  * @brief  The application entry point.
  *
  * @retval None
  */



void bootloaderSwitcher();


int main(void)
{
	serialNumber = uid[0] ^ uid[1] ^ uid[2];
  /* USER CODE BEGIN 1 */
  bootloaderSwitcher();
  /* USER CODE END 1 */

  /* MCU Configuration----------------------------------------------------------*/

  /* Reset of all periph
   * erals, Initializes the Flash interface and the Systick. */
  HAL_Init();

  /* Configure the system clock */
  SystemClock_Config();

  /* Initialize all configured peripherals */
  MX_GPIO_Init();
  MX_USART1_UART_Init();
  MX_USB_DEVICE_Init();
  /* USER CODE BEGIN 2 */
  HAL_UART_Receive_IT(&huart1, &Uart2RxFifo, UART_RX_FIFO_SIZE);
//  HAL_NVIC_SetPriority(USART1_IRQn, 2, 0);
  NVIC_EnableIRQ(USART1_IRQn);
  /* USER CODE END 2 */

  /* Infinite loop */
  /* USER CODE BEGIN WHILE */
  while (1)
  {
	  slCanCheckCommand();
  /* USER CODE END WHILE */

  /* USER CODE BEGIN 3 */

  }
  /* USER CODE END 3 */

}

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
/* USER CODE BEGIN 4 */
void HAL_UART_RxCpltCallback(UART_HandleTypeDef *huart){
	extern LinType_t lin_type;
	uint8_t rbyte = Uart2RxFifo;
	if (slcan_state == SLCAN_STATE_OPEN)
	{
		switch (lin_type)
		{
		case LIN_MASTER:
			open_lin_master_dl_rx(rbyte);
			break;
		case LIN_SLAVE:
			open_lin_slave_rx_header(rbyte);
		default: /* Monitor */
			lin_slcan_rx(rbyte);
			break;
		}
	}
	HAL_UART_Receive_IT(huart, &Uart2RxFifo, 1);
}

void HAL_UART_ErrorCallback(UART_HandleTypeDef *huart)
{

}

/* USER CODE END 4 */
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


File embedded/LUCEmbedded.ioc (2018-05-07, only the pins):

Mcu.UserName=STM32F042G4Ux
PA11.Signal=USB_DM
PA12.Signal=USB_DP
PA13.Signal=SYS_SWDIO
PA14.Signal=SYS_SWCLK
PB6.Signal=USART1_TX
PB7.Signal=USART1_RX

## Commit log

2018-02-14 KiCad project rename
    [CAN_BDC.dsn, LIN_USB_CONVERTER.kicad_pcb, LIN_USB_CONVERTER.sch]
2018-03-07 Kicad update
    [LIN_USB_CONVERTER.kicad_pcb, LIN_USB_CONVERTER.sch]
2018-03-14 frame reception fixes
    [LIN_USB_CONVERTER.kicad_pcb]
2018-03-17 Naming update
    [LIN_USB_CONVERTER.kicad_pcb, LIN_USB_CONVERTER.sch]
2018-04-03 PCB release
    [CAN_BDC-B.Cu.gbl, CAN_BDC-B.Fab.gbr, CAN_BDC-B.Paste.gbp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]
2018-05-07 Remove of galvanic spearator
    [LIN_USB_CONVERTER-B.CrtYd.gbr, LIN_USB_CONVERTER-B.Cu.gbl, LIN_USB_CONVERTER-B.Fab.gbr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]
2018-05-25 TJA package update
    [LIN_USB_CONVERTER-B.Cu.gbl, LIN_USB_CONVERTER-B.Mask.gbs, LIN_USB_CONVERTER-B.SilkS.gbo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]
2018-05-26 Panels add
    [LIN_USB_CONVERTER-B.CrtYd.gbr, LIN_USB_CONVERTER-B.Cu.gbl, LIN_USB_CONVERTER-B.Fab.gbr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]
2018-05-28 Usb holes update
    [LIN_USB_CONVERTER-B.Cu.gbl, LIN_USB_CONVERTER-B.Mask.gbs, LIN_USB_CONVERTER-B.SilkS.gbo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]
2019-03-09 Bugfixing for upper case
2021-04-07 fix type and reformat file to be compatible with PEP8
    [LUC.py]
2026-10-12 Firmware 3.3: LIN slave/master fixes, classic checksum, vendored openLIN, test suite
    Firmware fixes:
    - Reject frame rows with length > 8 instead of checking the stale stored
    length; one malformed row no longer blocks the table until power cycle
    - Reject rows when the 16-row table is full (was out-of-bounds write)
    - Terminate the copied command line so stale bytes of a previous longer
    command are not parsed as data
    - Restart UART reception after an overrun (HAL aborts IT reception on ORE);
    slave mode stopped after its first response at 9600 baud
    - Give the slave network layer its own slot table; it was reading the master
    table with a different layout and never matched any frame id
    - R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
2026-10-23 MCP server: let AI agents sniff and reverse-engineer a LIN bus
    ucanlintools.mcp_server (console script ucanlin-mcp, extra [mcp]):
    monitor_bus, detect_bus, LDF load/decode/encode, and send_frame /
    run_master / run_slave behind --allow-transmit. Reads the port directly
    so back-to-back frames are kept, filters the 0x3F start/stop echo, and
    has a --mock simulated bus. Offline tests, Dockerfile and glama.json
    for directory listings. ucanlintools 0.1.0.
2026-10-23 ucanlintools: keep back-to-back frames, LIN bit order, single-frame LDFs
    - LUC: the frame thread cleared the whole receive buffer after each frame,
    so frames arriving in the same USB read were lost; it also raced the
    byte thread on that buffer. Now lines are taken off one at a time under
    a lock, and parsing checks the length field.
    - LINFrame: encode/decode packed signals MSB first in declaration order
    and ignored bit_offset; they now use LIN bit order (LSB first at
    bit_offset), support signals wider than 8 bits, and no longer overwrite
    the LDF default values. Drops the bitstruct dependency.
    - LDF grammar: Signals/Frames sections with a single entry were inlined
    by lark and par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
2026-11-02 README: fix product photo link (.webp) and slot count (16)
    The product photo moved to ulc.webp on ucandevices.github.io; the old .png
    link returned 404. The firmware keeps 16 schedule rows (MAX_SLAVES_COUNT),
    verified on hardware: the 17th slot is rejected.
2026-11-03 Firmware 3.4: master slot delay measured from the start of the frame
    The master scheduler started a slot's delay only when the previous frame
    had ended: the counter was reset when the frame completed, and the ticks
    that pass while the UART transmit blocks inside the SysTick interrupt were
    not counted at all. Every slot was longer than configured by its frame
    time (+2 to +6 ms at 19200 baud), and an unanswered subscriber slot by the
    whole response timeout (+12 ms), so a schedule ran slower than its LDF.
    - Reset the slot counter when the header is sent, not when the frame ends
    - Add the frame's transmit time, computed from its bit count and the baud
    rate, for the SysTick ticks lost while th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
2026-11-03 Firmware 3.5: own USB VID/PID from pid.codes (1209:2779)
    The converter enumerated with ST's generic virtual COM port ID 0483:5740,
    shared with every STM32 CDC board, so host software could not tell a uLC
    from other devices by its USB ID. The project's ID from pid.codes,
    1209:2779 (https://pid.codes/1209/2779/), is now used. The device is
    still a USB CDC ACM device: Windows 10/11, Linux and macOS load their
    built-in driver, no driver installation is needed.
    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
2026-11-03 ucan-lin-mcp 0.1.2: detect firmware 3.5, 16 schedule slots
    - Auto-detect the converter by its pid.codes ID 1209:2779 (firmware 3.5)
    as well as the old 0483:5740 (the change is in python_lib, which the
    package bundles at build time)
    - The firmware holds 16 schedule rows, not 15
    - Version 0.1.2 in the package and the MCP Registry entry
2026-11-03 Firmware 3.6: trim the internal 48 MHz clock to USB with CRS
    The board has no crystal: the internal HSI48 RC oscillator clocks the CPU,
    USB and the LIN UART, and drifts with temperature. The Clock Recovery
    System, made for crystal-less USB on the STM32F042, was never enabled.
    It now trims HSI48 to the host's 1 ms USB SOF, so the LIN baud rate and
    the master slot timing hold their accuracy over temperature.
    Checked with a test-only build reporting the CRS registers: it reaches
    sync within seconds (SYNCOK, no errors afterwards) and moved the trim from
    32 to 35 on one converter. Full suite 63/63 in both roles.
2026-11-03 Firmware 3.7: slave no longer loses the frame after an unanswered header
    When the slave subscribed a frame that nobody answered, it waited for that
    frame's data. The next header's break byte (0x00) arrived first and was
    counted as data; the break itself was then detected, but the data count
    was not reset. The following frame was read starting at count 1, so its
    last data byte was taken as the checksum and the frame was dropped. With
    a subscribed slot that stays unanswered every cycle, the slave never saw
    the frame after it (0 of 17 in the test).
    - Reset the data count when a break is detected
    - Firmware version 3.7
    - Regression test test_slave_subscribed_to_unanswered_header_keeps_next_fram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
2026-11-03 Firmware 3.8: monitor no longer drops back-to-back frames
    The monitor does not know a frame's length, so it ends a frame after about
    3 ms of bus idle. When the next frame's break arrived sooner (one-shot
    frames sent as fast as the converter acknowledges them, about 4 ms apart
    at 19200 baud), the reception was reset and the previous frame was lost,
    roughly every other frame (15 of 32 received).
    - On a break, report the frame still being received (checksum checked as
    before); the break's 0x00 byte is not counted as data
    - Firmware version 3.8
    - Regression test test_monitor_reports_back_to_back_frames (fails on 3.7)
    Full suite 66/66 with both role assignments; CANgaroo uLC driver hardware
    t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
2026-11-03 README: name the MCU as STM32F042
    The board uses an STM32F042 in UFQFPN-28, not the STM32F042C6.
2026-11-03 CI: build the firmware and run the Python tests
    Command-line Makefile for the firmware with the same sources and flags
    as the STM32CubeIDE project. The workflow builds it with Ubuntu's
    arm-none-eabi-gcc, reports flash usage and uploads the .bin. The Python
    job runs the test suite (hardware tests skip), checks the MCP package
    copies match python_lib and builds the MCP package.
2026-11-03 CI: smoke-test the MCP package instead of diffing generated copies
    mcp_package/setup.py copies its modules from python_lib at build time,
    so the copies are not in git. Build the wheel, install it in a clean
    venv and run ucan-lin-mcp --help.

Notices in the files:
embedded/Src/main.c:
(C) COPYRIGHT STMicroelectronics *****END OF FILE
